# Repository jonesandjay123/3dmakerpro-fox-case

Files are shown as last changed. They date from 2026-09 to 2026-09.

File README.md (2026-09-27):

# 3dmakerpro-fox-case

A compact, low-profile, 3D-printable hard case for the **3DMakerpro FOX** scanner body.
V4 is **scanner only**; the cable and charger stay in the original accessory box for now.

| Closed | Lift-out access | One A1 mini plate |
|---|---|---|
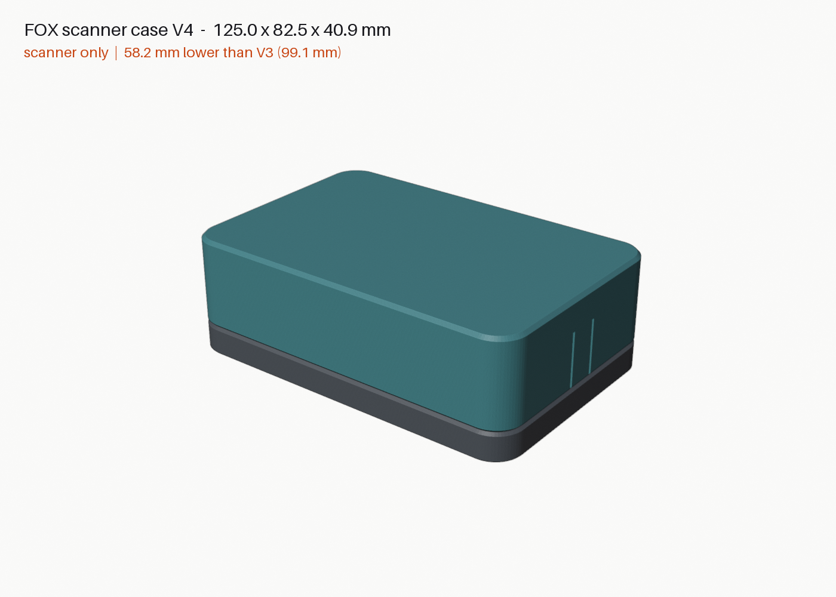
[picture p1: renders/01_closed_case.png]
closed
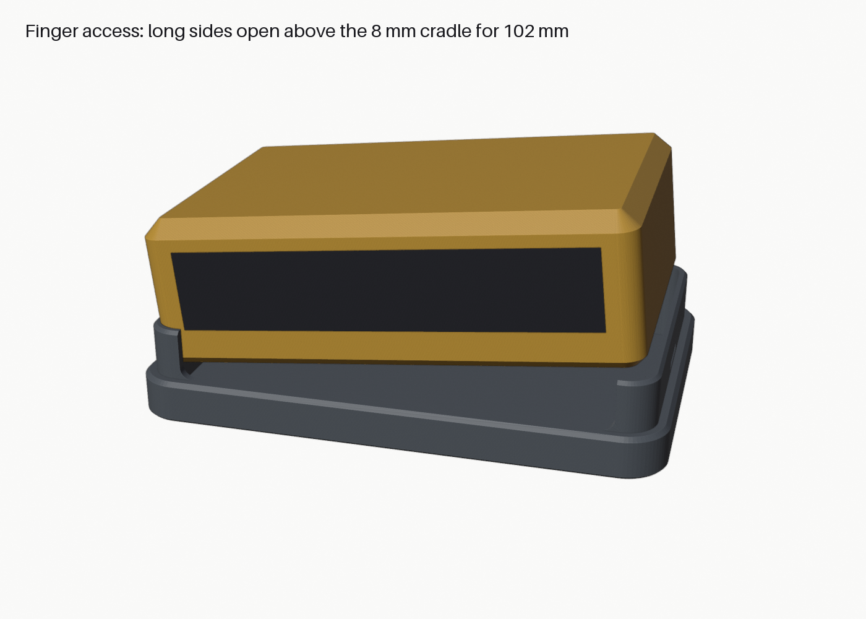
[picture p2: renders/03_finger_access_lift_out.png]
access
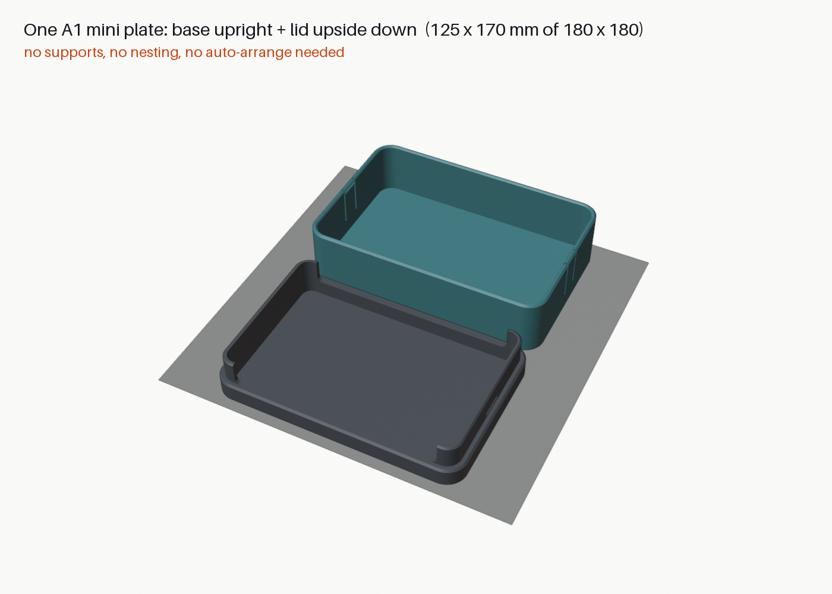
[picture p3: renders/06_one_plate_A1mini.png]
plate
|  |  |  |

## Status: V4 modelled and validated in CAD (not yet printed)

| | V4 |
|---|---|
| **Outside** | **125.0 × 82.5 × 40.9 mm** (58 mm lower than the V3 full-kit case) |
| **FOX cavity** | **115.5 × 73.0 mm** (R 5.25), from the physical fit test; 36.5 mm floor → lid ceiling |
| **Clearance** | ~1.5 mm above the FOX (35 mm stand-in); 0.3 mm per side; lens window faces open air |
| **Access** | shallow 8 mm cradle, **102 mm finger windows** on both long sides |
| **Lid** | low sleeve with **2 snap tabs** that click into the base (est. ~22 N to open) |
| **Print** | **one plate, one job, no supports**: base upright + lid upside down |
| **Filament** | ~89–102 g PLA |

Details, height budget, retention, validation and test plan: [`docs/design.md`](docs/design.md).

## Print

Open **`exports/fox_case_v4_A1mini_one_plate.3mf`** in Bambu Studio. The parts are already
placed; don't auto-arrange. Settings: 0.2 mm layers, 3 walls, 15 % infill, supports off, no brim.

Optional first: `exports/fox_fit_test_cradle_ring_v3.stl` (~9 g) to confirm the 73.0 mm width.

## Files

| Path | Contents |
|---|---|
| `scripts/build_fox_case.py` | Parametric build: named parameters; builds, validates, exports STL/3MF, saves the .blend |
| `scripts/run_all.py` / `scripts/render_views.py` / `scripts/annotate_renders.py` | Full pipeline / renders / dimension labels |
| `cad/fox_case.blend` | Editable Blender source |
| `exports/fox_case_v4_{base,lid}.stl` | Parts in print orientation |
| `exports/fox_case_v4_A1mini_one_plate.3mf` / `fox_case_v4_assembled.3mf` | One-plate job / assembled model |
| `exports/validation_report.json` | Parameters, measured dimensions, mesh, support, retention, plate and assembly checks |
| `renders/` | Closed, open, lift-out, exploded, sections, one-plate, snap tab, fit ring |
| `docs/design.md` | V4 design notes |
| `archive/v2`, `archive/v3` | Earlier full-kit (scanner + accessories) versions; also git tags `v1`–`v3` |
| `reference/` | Original photos, fit-test photos, V3 concept, third-party stand (unaltered) |

## Rebuild after changing a parameter

```bash
/Applications/Blender.app/Contents/MacOS/Blender -b cad/fox_case.blend --python scripts/run_all.py
```

```bash
uv run --with pillow python scripts/annotate_renders.py
```

Key parameters: `FOX_CAVITY_LENGTH/WIDTH`, `FOX_INTERNAL_HEIGHT`, `CRADLE_HEIGHT`, `WALL`, `FLOOR`,
`LID_WALL`, `LID_TOP`, `LID_CLEARANCE`, `TOWER_HEIGHT`, `RETENTION_ENGAGEMENT`, `FINGER_WINDOW_LENGTH`,
`PLATE_GAP`. `TOTAL_CASE_HEIGHT` is derived from them.

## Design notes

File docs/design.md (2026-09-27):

# FOX scanner case — design notes (V4: scanner-only, low profile)

**Scope:** a compact, protective hard case for the **3DMakerpro FOX scanner body only**. The cable
and charger are out of scope for now; they stay in the original black accessory box.

All geometry comes from [`scripts/build_fox_case.py`](../scripts/build_fox_case.py). Edit a parameter
and re-run it (see [README](../README.md)). Every number below is from `exports/validation_report.json`.

## V4 at a glance

| | V4 |
|---|---|
| **Outside** | **125.0 × 82.5 × 40.9 mm** (V3 full kit was 99.1 mm tall, so **−58.2 mm / −59 %**) |
| **FOX cavity** | **115.5 × 73.0 mm, R 5.25** (fit-test derived; measured on the model) |
| **FOX vertical space** | **36.5 mm**, floor → lid ceiling. With a 35 mm stand-in body that leaves **1.5 mm** above the FOX; the lid never touches it |
| **Cradle** | 8 mm capture height; **102 mm finger windows on both long sides** |
| **Lid retention** | 2 printed cantilever snap tabs (lid short ends) that click into grooves in the base end towers |
| **Print** | **one A1 mini plate, one job, no supports**: base upright + lid upside down, side by side |
| **Material** | 111 g solid-equivalent; expect **~89–102 g** at 3 walls / 15 % infill |

```
     ┌────────────────── LID: 2.4 wall, 2.4 flat top, snap tab at each end ──┐   z 40.9
     │                        1.5 mm clear above FOX                          │   z 38.5 ceiling
     │ ▐tower▌            FOX lies flat (36.5 mm space)            ▐tower▌    │
     └─▐     ▌▁▁▁▁▁ 8 mm cradle band; long sides open above ▁▁▁▁▁▐     ▌───┘   z 10.0 lid seat
       BASE: 2.0 floor · band · low C-shaped end towers (to z 22) with snap grooves    z 0
```

---

## 1. Evidence

* **Settled by the physical fit test** (printed ring, 115.5 × 72.5, R 5.25):
  - length fine with ~1 mm play;
  - width lightly gripped, so V3 widened it to **73.0**;
  - corners and the 8 mm cradle looked good.
* **FOX space 36.5 mm** is your measured requirement.
* V4 does **not** re-estimate the FOX from photos, the spec sheet or the third-party stand. That
  history is in `archive/` and the git tags.
* The FOX stand-in used for clearance checks (`FOX_PROXY` 114.4 × 72.4 × 35, R 5) is inferred. It
  isn't a design input.
* **Not yet physically verified:** the 73.0 mm width. The printed ring was 72.5.
  `exports/fox_fit_test_cradle_ring_v3.stl` is still exported for that check.

## 2. What changed from V3

| V3 (full kit) | V4 (scanner only) |
|---|---|
| Accessory tray 112.5 × 70 × 56 above the FOX | **removed**; accessory parameters no longer exist in the build |
| Towers 36.5 mm tall as a tray seat, plus tray lips | **towers only 20 mm** (lid guide + snap grooves), no lips, 0.8 mm lead-in |
| Lid ceiling above the tray (99.1 mm total) | **lid ceiling sits directly above the FOX space: 40.9 mm total** |
| 2 print jobs | **1 job, 1 plate** |
| Grey renders | teal lid / charcoal base, so V4 renders are easy to tell apart |

Kept as-is:
- cavity and corner logic;
- 8 mm cradle band and 102 mm finger windows;
- 1.5 mm tower stubs and R3 window corners, which keep the lens window clear;
- the snap-tab latch;
- the validation and export pipeline.

## 3. Height budget: 40.9 mm

| Layer | mm | |
|---|---|---|
| Base floor | 2.0 | 10 layers; the case bottom |
| FOX space (floor → lid ceiling) | 36.5 | measured requirement; includes the clearance above the FOX |
| Lid top | 2.4 | printed on the bed. At 2.4 mm a ~5 kg press on the middle of the lid is estimated to deflect ~0.5 mm (2.0 mm would be ~0.8 mm), well inside the 1.5 mm gap |
| **Total** | **40.9** | |

Nothing else stacks: the lid seats on the base band shoulder at z = 10, and its sleeve overlaps
the towers. Going lower means eating into the measured 36.5 mm, which V4 deliberately doesn't do.

## 4. Parts

### Base (125.0 × 82.5 × 22.0, printed upright)
* A **2.0 mm floor** with a **solid 10 mm band**, which has 4.75 mm walls on the long sides.
* **Cavity 115.5 × 73.0, R 5.25** with a flat floor.
* **Long sides open above the 8 mm cradle for 102 mm**, so you pinch the FOX by its long sides
  and lift it out (`renders/03_finger_access_lift_out.png`).
* The **C-shaped end towers** (2.0 mm wall) rise to z = 22 and guide the lid. Each carries a
  **detent groove** on its end face and a 0.8 mm lead-in chamfer on top. The towers stop 1.5 mm
  past the corner arcs, so the **lens window faces open air**. The sensor face stays ≥ 0.67 mm
  from the base; only the bezel sits below the 8 mm band.

### Lid (125.0 × 82.5 × 30.9, printed upside down)
* A **2.4 mm sleeve with a 2.4 mm flat top**. It has 0.35 mm clearance per side over the towers
  and a 0.8 mm lead-in at the mouth, and it seats on the base band at z = 10. Matching 1 mm
  chamfers at the joint form a thumb groove.
* Inside there is **1.5 mm above the FOX** (35 mm stand-in) and **2.45 mm in front of the sensor
  face**. The lid doesn't touch the FOX, even with the FOX lifted 0.5 mm.

### Retention: snap tabs
* **Tabs.** Two 1 mm slots, 20 mm long, at each lid end free a **10 mm × 2.4 mm cantilever tab**.
* **Bump.** Each tab has an inward bump that overlaps the tower face by
  **`RETENTION_ENGAGEMENT` = 0.4 mm**. Its lower ramp is 30° from vertical, for an easy click shut.
  Its upper ramp is 45°: firm to open, and the steepest face that prints without support.
* **Groove.** The matching groove in the base is 0.2 mm oversize. With the lid closed the bump
  sits in it without clashing.
* **Estimate** (PLA, beam theory, order of magnitude):
  - **closing ≈ 13 N**;
  - **opening ≈ 22 N** (≈ 2.3 kgf);
  - tab strain 0.36 %.
  - The FOX plus base weigh ~0.25 kg, so lifting the closed case by the lid won't drop the base.
* **Tuning:** use 0.3 for a lighter feel (~17 N to open), or 0.5 for a firmer hold (~28 N).
* The latch adds no external structure: the tabs are flush with the lid wall.

## 5. Printing: one A1 mini plate

* `exports/fox_case_v4_A1mini_one_plate.3mf`: **base upright** and **lid upside down**, side by
  side. It uses **125 × 170 mm** of the 180 × 180 bed, with a 5 mm gap between parts and ≥ 5 mm
  margins. Open it as-is; **no auto-arrange needed**.
* **Support-free.** 0 mm² of down-facing surface steeper than 45° on both parts, and no bridges.
* **Big first layers.** The base puts 9,990 mm² on the bed and the lid 9,750 mm², so no brim is needed.
* Settings: 0.2 mm layers, 3 walls, 15 % infill, PLA or PETG.
* Filament: base 48 g + lid 63 g = **111 g solid-equivalent**, so expect **~89–102 g**.
* Individual STLs (`fox_case_v4_base.stl`, `fox_case_v4_lid.stl`) are exported in the same
  orientations.

## 6. Validation

| Check | Result |
|---|---|
| Cavity (measured by ray cast on the model) | **115.5 × 73.0 mm** ✓ |
| Floor → lid ceiling (measured) | **36.5 mm** ✓ |
| FOX top clearance (35 mm stand-in) | **1.5 mm**; `lid_presses_on_fox: false` |
| FOX stand-in ↔ cradle wall | 0.3 mm per side (0.55 per end) |
| Sensor face ↔ base / lid | 0.67 / 2.45 mm |
| Finger access | 102 mm on both long sides, above the 8 mm band |
| Lid / base fit | 0.35 mm per side on the towers; lid seats on the band; no clash |
| Positive retention | bump seated in groove, 0.4 mm engagement |
| Watertight / non-manifold / self-intersections / islands | 0 / 0 / 0 / 1 on every part (also on re-imported STLs) |
| Min wall (1st percentile) | base 2.0, lid 2.4 |
| Supports | none (both parts `support_free: true`) |
| Per-part A1 mini fit | ✓ base 125 × 82.5 × 22.0, lid 125 × 82.5 × 30.9 |
| One-plate fit | ✓ bbox 27.5–152.5 × 5–175 mm, 5 mm between parts, no clash |
| Outside | **125.0 × 82.5 × 40.9 mm** |
| Material | 111 g solid-equivalent, ~89–102 g sliced |

## 7. Assembly and use

1. Drop the FOX in, sensor face toward either long side.
2. Push the lid straight down until both tabs click.
3. To open, hold the base band and pull the lid up.
4. Lift the FOX out by pinching its long sides through the windows.

## 8. Remaining physical tests

1. **Width 73.0.** Print `fox_fit_test_cradle_ring_v3.stl` (~9 g) or the full plate, and confirm
   the FOX drops in and lifts out without friction.
2. **Top clearance.** 36.5 mm is reserved. If the FOX itself is close to 36.5 mm tall, there's
   almost no Z margin; tell me and I'll add some (+1 mm on the case).
3. **Snap feel.** Tune `RETENTION_ENGAGEMENT` (0.3–0.5) to taste.
4. **Lens window vs the 8 mm band** (fine in the ring test).

## 9. History

| | V1 | V2 | V3 | **V4** |
|---|---|---|---|---|
| Scope | FOX + accessories | same | same | **FOX only** |
| Outside (mm) | 125 × 82 × 113.3 | 125 × 82 × 130.5 | 125 × 82.5 × 99.1 | **125 × 82.5 × 40.9** |
| Cavity | 115.5 × 72.5 | 115.5 × 72.5 | 115.5 × 73.0 | **115.5 × 73.0** |
| Print | 2 plates | 1 plate (nested) | 2 plates | **1 plate** |
| Retention | slip | slip | snap tabs | **snap tabs** |

* Git tags `v1`, `v2`, `v3`.
* `archive/v2/` and `archive/v3/` hold the printable files, key renders, and V3's design notes
  and build script.

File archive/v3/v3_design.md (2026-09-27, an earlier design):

# FOX carrying case — design notes (V3: compact)

Goal: one rigid, compact, FDM-printable case that carries the **3DMakerpro FOX scanner, its
cable and its charger together**. Printer: Bambu Lab A1 mini (180 × 180 × 180 mm per part).

All geometry comes from [`scripts/build_fox_case.py`](../scripts/build_fox_case.py). Edit a parameter
and re-run it (see [README](../README.md)). Numbers below are current V3 values, taken from
`exports/validation_report.json`.

## V3 at a glance

| | V3 |
|---|---|
| **Outside** | **125.0 × 82.5 × 99.1 mm** (V2 was 130.5 mm tall, so **−31.4 mm**) |
| **FOX cavity** | **115.5 × 73.0 mm, R 5.25**, from the physical fit test |
| **FOX vertical space** | **36.5 mm** clear (floor top → tray underside) |
| **Accessory tray** | **112.5 × 70.0 × 56 mm inside**, **one open bin, no divider** |
| **Lid retention** | 2 printed cantilever snap tabs (lid short ends) that click into grooves in the base |
| **Print** | 2 jobs, no supports: (A) base + tray, (B) lid upside down |
| **Material** | ≈ 249 g solid-equivalent; expect ~195–225 g at 3 walls / 15 % infill |

---

## 1. Evidence (V3 order of authority)

1. **Physical fit test (new, primary).** You printed the V2 ring (cavity 115.5 × 72.5, R 5.25):
   * **Length 115.5:** a little over ~1 mm total free play. Kept.
   * **Width 72.5:** it fits, but grips the FOX lightly. **Widened by 0.5 → 73.0**, so the FOX drops in
     without friction.
   * **Corners R 5.25:** behaved well. Kept.
   * **Cradle height (8 mm band):** looked right. Kept.
2. **Your physical height measurement:** reserve **36.5 mm** for the scanner region. It's used as
   the clear height from the base floor to the tray underside.
3. **Your accessory measurement:** the charger is **~56 wide × 52 tall**. Charger + cable laid out
   in a row need ~56 × 52 × 172 mm. **Your decision:** keep the 125 × 82 footprint, don't reproduce
   the 172 mm row. The tray is one open bin **~56 mm deep** (charger at one end, cable coiled freely
   beside it), with a total height target of ~98–100 mm.
4. The V1/V2 photo analysis, third-party stand STL and spec sheet are superseded wherever they
   conflict with 1–3. The history is in §9.

The FOX stand-in body used for clearance checks (`FOX_PROXY` = 114.4 × 72.4 × 35, R 5) is
*inferred* from the ring test. It isn't a design input.

## 2. What changed from V2 and why

| V2 driver | V3 |
|---|---|
| Whole case on one plate, no supports, at any height cost (roof + nested tray → 130.5 mm) | **Dropped.** Two print jobs are fine; carrying a smaller case every day matters more |
| Tray volume ≥ cardboard box (539 cm³) | **Dropped.** Tray sized for the real charger (52 tall) + free cable coil |
| Cavity 115.5 × 72.5, space 36.5 | **115.5 × 73.0** (fit test), 36.5 kept as a hard requirement |
| Slip-fit lid | **Snap-tab retention** |
| Lid printed mouth-down with a 45° roof | Lid printed **upside down with a flat top**: big first layer, no bridge, lower |
| Floor 2.4, tray floor 2.0, lid top 2.4 | 2.0 / 1.6 / 2.0 (height trimmed where it isn't structural) |

## 3. Height budget: why 99.1 mm is the practical minimum

| Layer (bottom → top) | mm | Why it can't shrink |
|---|---|---|
| Base floor | 2.0 | 10 solid layers; also the case bottom |
| FOX space | 36.5 | your measured requirement |
| Tray floor | 1.6 | 8 layers; the tray is stiffened by its 2 mm walls |
| Tray inner depth | 56.0 | charger 52 + ~4 headroom (you chose 55–58; 56 used) |
| Tray rim → lid ceiling | 1.0 | limits tray lift; keeps the FOX captured |
| Lid top | 2.0 | printed on the bed; 10 layers |
| **Total** | **99.1** | |

The only big lever left is the tray depth: each 1 mm off `ACCESSORY_TRAY_HEIGHT` takes 1 mm off
the case. If your charger can lie on a thinner face, set the parameter and rebuild (at a 34 mm
depth the case would be ~77 mm tall).

## 4. Architecture

```
        ┌───────────────── LID (flat top, 2.4 wall, snap tabs at both ends) ─┐  z 99.1
        │  ┌──────── TRAY: ONE open bin, 112.5 × 70 × 56 inside ────────┐   │  z 96.1 rim
        │  │  charger (52 tall) at one end · cable coiled freely beside   │   │
        │  └──────────────────── tray floor 1.6 ──────────────────────────┘   │  z 38.5
        │ ▐tower▌      FOX lies flat, 36.5 mm space            ▐tower▌      │
        └─▐     ▌▁▁▁▁ 8 mm cradle band (long sides open above) ▁▁▐     ▌─────┘  z 10.0 lid seat
          BASE: 2.0 floor · band · C-shaped end towers · snap grooves         z 0
```

* **Base.** A 2.0 mm floor and a solid 10 mm band (walls 4.75 mm on the long sides). Above it, two
  **C-shaped end towers** (2.0 wall) rise to the tray seat at z = 38.5. **Both long sides are open
  above the 8 mm cradle for 102 mm**, so you pinch the FOX by its long sides to lift it out. The
  tower stubs stop 1.5 mm past the corner arcs, so the lens window faces open air.
  2.5 mm lips on the tower tops locate the tray and carry a 0.6 mm lead-in for the lid.
* **FOX cavity 115.5 × 73.0, R 5.25** with a flat floor. With the stand-in body that leaves
  ~0.55 mm per end and ~0.3 mm per side. The sensor face stays ≥ 0.67 mm clear of the base and
  2.45 mm clear of the lid; only the bezel is below the 8 mm band.
* **Tray.** **One open bin with no divider, rib or molded pocket.** It's 116.5 × 74.0 × 57.6 mm
  outside and **112.5 × 70.0 × 56 mm inside (≈ 440 cm³)**. It sits on the towers, 1.5 mm
  above the FOX, so it also keeps the FOX from lifting out of the cradle.
* **Lid.** A 2.4 mm sleeve with 0.35 mm clearance per side over the towers and a 0.8 mm lead-in at
  the mouth. It rests on the base band shoulder at z = 10. A matching 1 mm chamfer at the joint
  forms a thumb groove.

### 4.1 Lid retention: snap tabs

* **Tabs.** Each short end of the lid has two 1 mm slots, 20 mm long from the mouth up. They free
  a **10 mm wide, 2.4 mm thick cantilever tab**.
* **Bump.** Near the tab's free end, an inward bump stands **0.35 + 0.4 mm** proud of the lid wall.
  The lower ramp is 30° from vertical, for easy closing. The upper ramp is 45°, which is firm to
  open and is also the steepest face the lid can print without support.
* **Groove.** A matching groove, 0.2 mm oversize, is cut into each base tower end wall. The bump
  overlaps the tower face by **0.4 mm**, and that overlap is the click.
* **Beam estimate** (PLA, E ≈ 3.5 GPa, μ ≈ 0.3, order of magnitude only):
  - **closing** ≈ 13 N total;
  - **opening** ≈ 22 N total (≈ 2.3 kgf);
  - tab-root strain 0.36 %, far below PLA's limit.

  The FOX plus base weigh ~0.3 kg, so the base will not fall away when you lift the closed case by
  the lid. You open it deliberately by holding the band and pulling the lid.
* **Tuning:** `LID_RETENTION["engage"]` (0.4). Use 0.3 if it's too stiff, or 0.5 for a firmer hold.

See `renders/07_snap_tab_section.png` (bump seated in the groove) and `07b_lid_underside_tabs.png`.

## 5. Printing

| Job | Part | Orientation | First layer | Supports |
|---|---|---|---|---|
| **A** | Base (125 × 82.5 × 41.0) | upright, floor on bed | 9,990 mm² | none |
| **A** | Tray (116.5 × 74.0 × 57.6) | upright, floor on bed | 8,370 mm² | none |
| **B** | Lid (125 × 82.5 × 89.1) | **upside down**, flat top on bed | 9,750 mm² | none |

* Ready-made plates: `exports/fox_case_v3_plate_A_base_and_tray.3mf` and
  `exports/fox_case_v3_plate_B_lid.3mf`. Individual STLs are already in print orientation.
* **Support-free.** 0 mm² of down-facing surface steeper than 45° on every part, and no bridges.
  The only non-vertical features:
  - the 45° release ramps on the lid bumps and in the base grooves;
  - the ≤45° chamfers;
  - the finger-window bottoms, which curve *away* from the material.
* Suggested settings: 0.2 mm layers, 3 walls, 15 % infill, PLA or PETG, no brim needed.
* **Material:** base 56 + tray 68 + lid 126 = **249 g solid-equivalent**. Expect **~195–225 g**
  sliced. Use the slicer's number for time.

## 6. Validation (`exports/validation_report.json`)

| Check | Result |
|---|---|
| FOX cavity | 115.5 × 73.0 mm, R 5.25 ✓ |
| FOX vertical space | 36.5 mm ✓ (stand-in 35 mm body → 1.5 mm to the tray) |
| FOX stand-in ↔ cradle | 0.3 mm per side, no clash |
| Sensor face ↔ base / lid | 0.67 / 2.45 mm |
| Finger access | 102 mm windows, both long sides, above the 8 mm band |
| Tray is divider-free | **568 / 568** grid rays dropped into the tray reach the floor unobstructed |
| Charger (52 × 56 × 52) + cable-coil stand-in (54 × 64 × 40) | both fit side by side, with no clash with each other, the tray or the lid; charger top 4.85 mm below the lid |
| Lid / base retention | bump seated in groove without clash; 0.4 mm engagement |
| Watertight / islands / self-intersections | 0 non-manifold edges, 1 island, 0 self-intersections on every part (also re-checked on re-imported STLs) |
| Min wall (1st percentile) | base 1.2 (lips), tray 1.6 (floor), lid 2.0 (top) |
| A1 mini per part / plates | all ✓; plate A 125 × 164.5, plate B 125 × 82.5 |
| Assembly clashes | none (resting contacts checked with a 0.02 mm lift) |

**What the checks don't prove.** The charger and cable stand-ins show the space is
*plausible*. They are not a packing proof. The charger's third dimension (depth) wasn't measured
and is assumed to be ≤ 52 mm. The cable's real coiled shape varies.

## 7. Assembly and use

1. Drop the FOX into the base cradle, sensor face toward either long side.
2. Put the tray on the towers (it drops between the lips). Charger at one end, cable coiled freely.
3. Push the lid down until both tabs click. To open, hold the base band and pull the lid up.

## 8. What still needs physical testing

1. **Width 73.0.** Optionally reprint `exports/fox_fit_test_cradle_ring_v3.stl` (~9 g) to confirm
   the FOX now drops in and lifts out freely.
2. **Charger + cable in the 112.5 × 70 × 56 tray.** Especially the charger's depth, and whether the
   cable coils into the ~58 × 70 mm left beside it.
3. **Snap-tab feel.** How firm it is to open and close. Tune `engage`.
4. **FOX top clearance.** 36.5 mm is reserved. If the FOX itself is close to 36.5 mm tall, there's
   no Z margin, so tell me and I'll add some.
5. **Lens window vs the 8 mm band** (it looked fine in the ring test).

## 9. History

| | V1 | V2 | **V3** |
|---|---|---|---|
| Outside (mm) | 125 × 82 × 113.3 | 125 × 82 × 130.5 | **125 × 82.5 × 99.1** |
| FOX cavity | 115.5 × 72.5 | 115.5 × 72.5 | **115.5 × 73.0** (fit-tested) |
| Accessory tray | 539 cm³ (box volume) | 539 cm³ | **one open bin, 56 deep** |
| Print | 2 plates | 1 plate, nested | **2 plates** |
| Retention | slip fit | slip fit | **snap tabs** |

* V1 and V2 are tagged in git (`v1`, `v2`).
* V2's printable files and key renders are kept in `archive/v2/`. That includes the ring used for
  the physical test: `archive/v2/fox_fit_test_cradle_ring.stl`.
* V1/V2 evidence work (perspective-corrected photo measurements, third-party stand analysis:
  113.0 mm between its lips) is in the git history of this file.

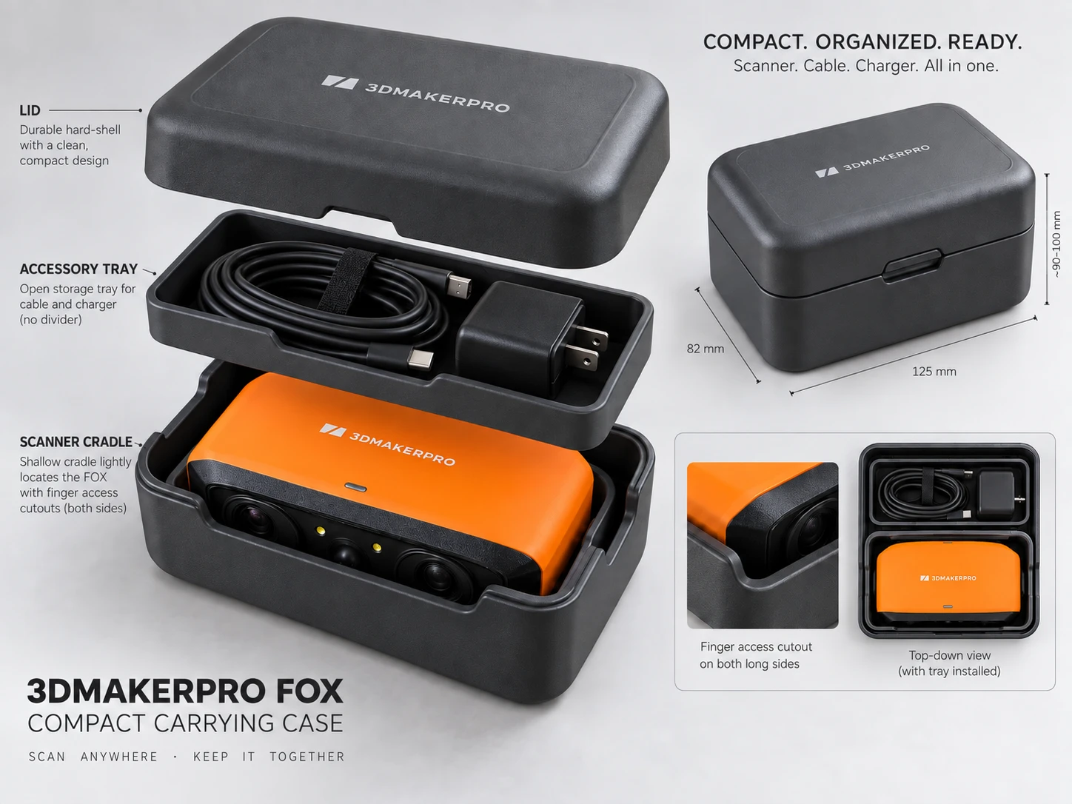
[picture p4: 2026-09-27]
reference/concept/v3_concept_no_divider.webp

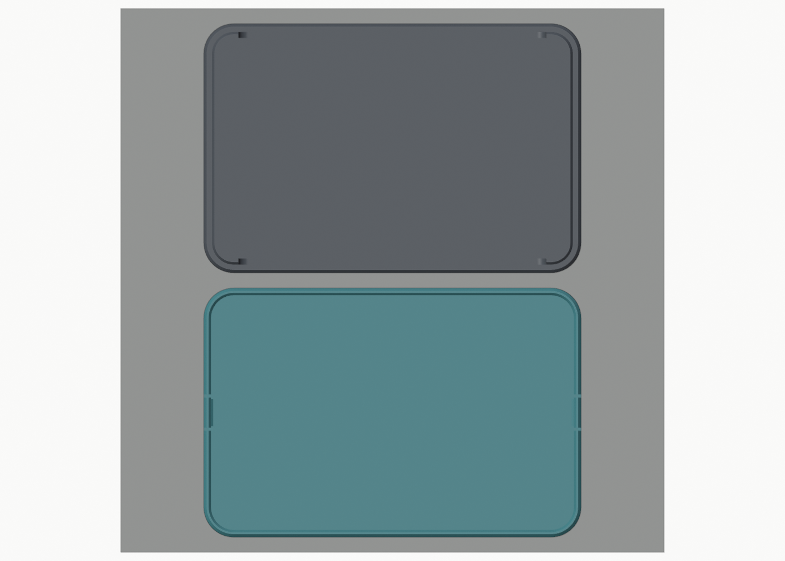
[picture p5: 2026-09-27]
renders/06b_one_plate_top.png

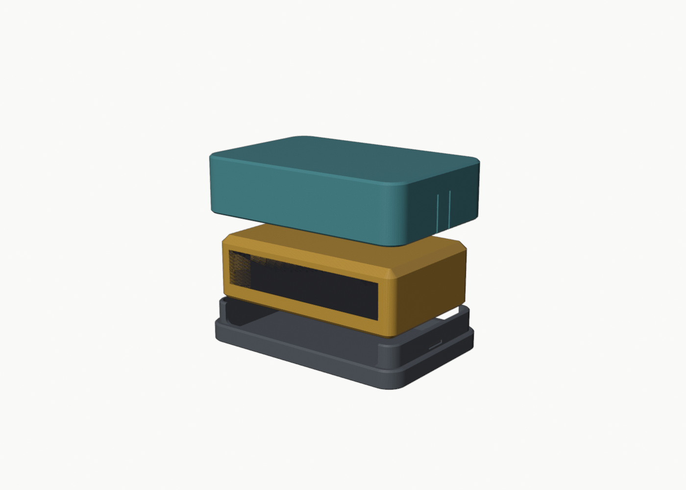
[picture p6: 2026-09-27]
renders/04_exploded.png

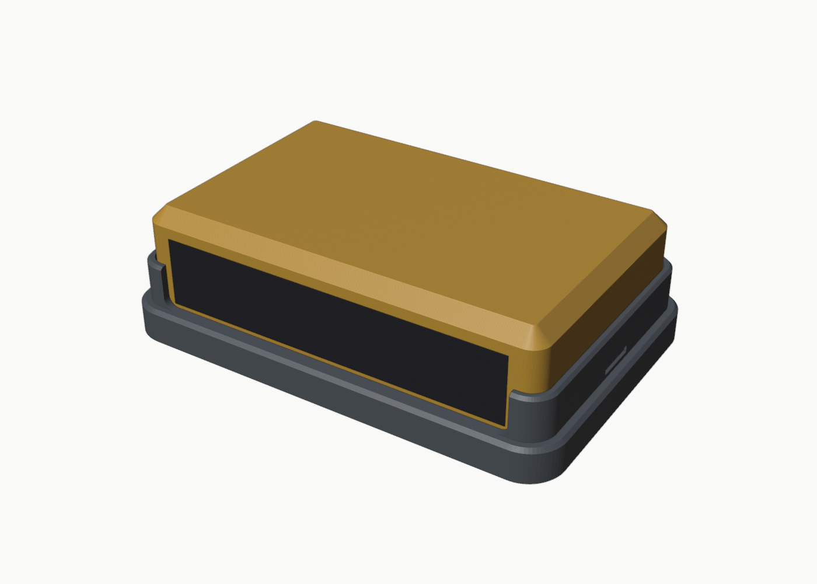
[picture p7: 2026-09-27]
renders/03b_fox_in_cradle.png

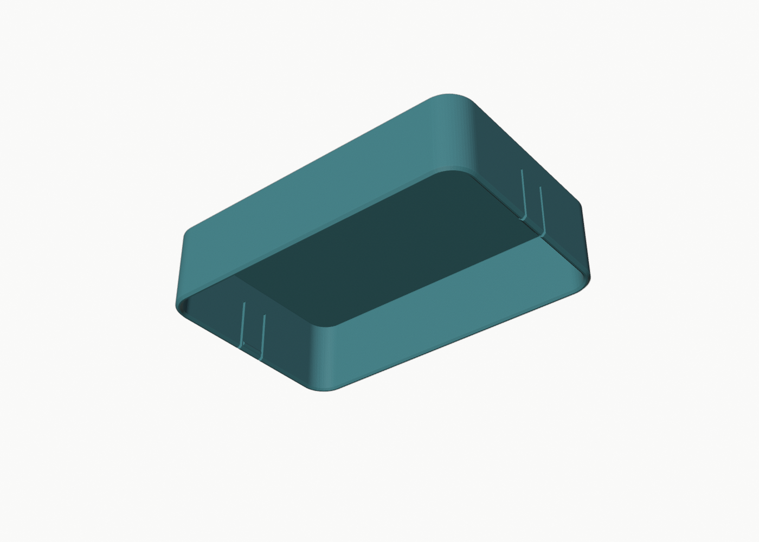
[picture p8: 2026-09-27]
renders/07b_lid_underside_tabs.png

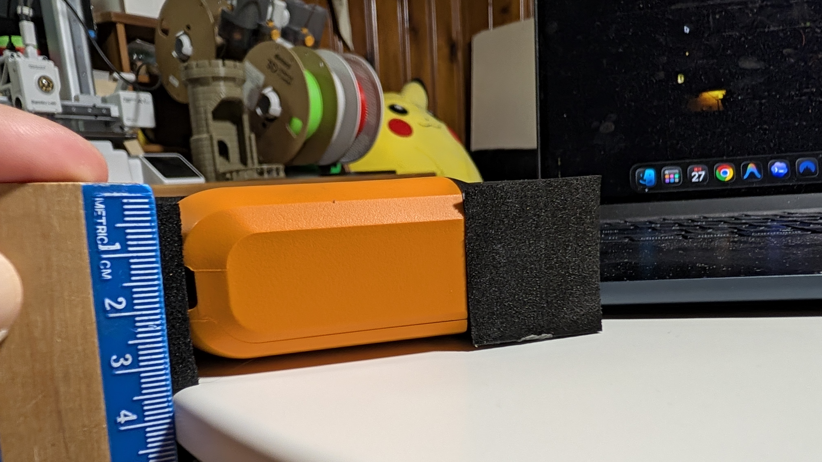
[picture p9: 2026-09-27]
reference/photos/PXL_20260927_174231056.MACRO_FOCUS.jpg

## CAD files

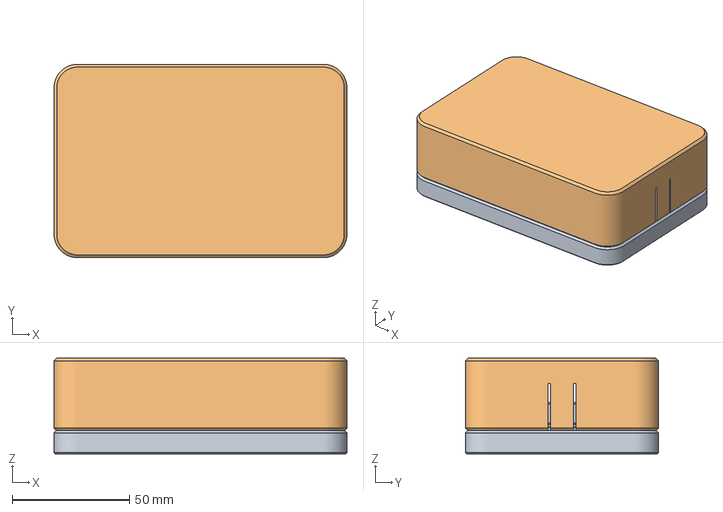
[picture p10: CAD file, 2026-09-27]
exports/fox_case_v4_assembled.3mf
125.0 x 82.5 x 40.9 mm
Base
Lid

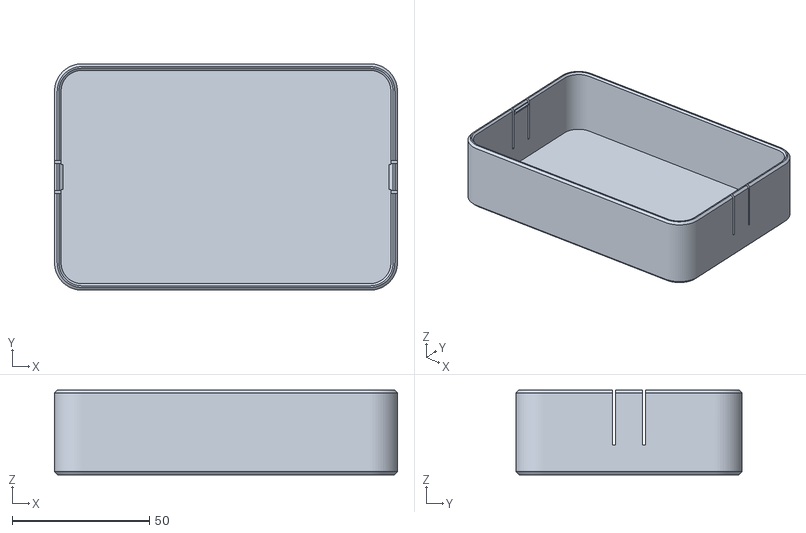
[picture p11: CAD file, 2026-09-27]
exports/fox_case_v4_lid.stl
125.0 x 82.5 x 30.9

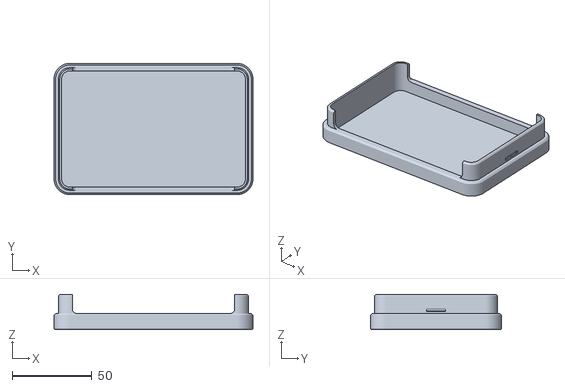
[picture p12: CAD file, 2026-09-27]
exports/fox_case_v4_base.stl
125.0 x 82.5 x 22.0

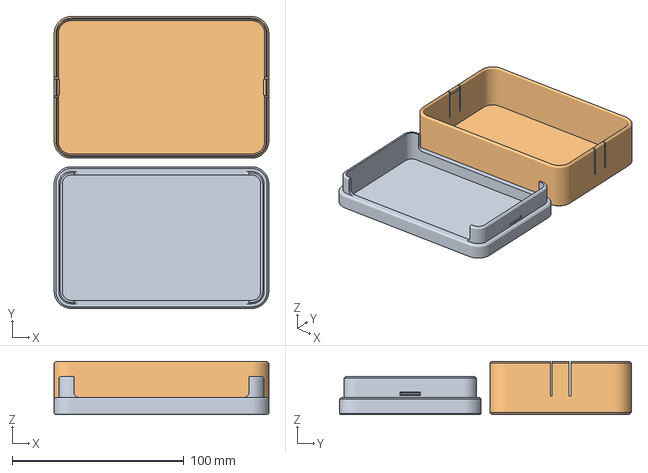
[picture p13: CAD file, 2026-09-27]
exports/fox_case_v4_A1mini_one_plate.3mf
125.0 x 170.0 x 30.9 mm
Base
Lid

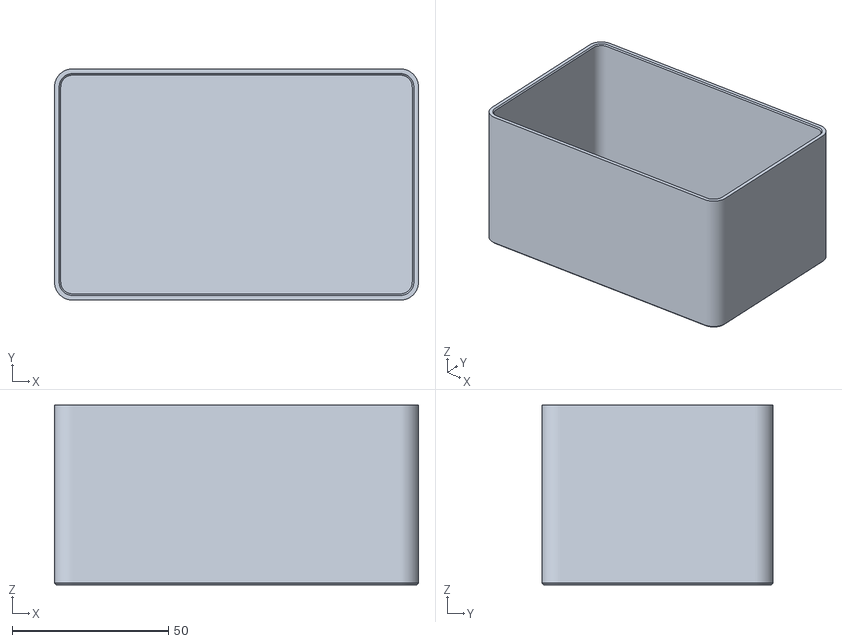
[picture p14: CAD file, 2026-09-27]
exports/fox_case_v3_accessory_tray.stl
116.5 x 74.0 x 57.6

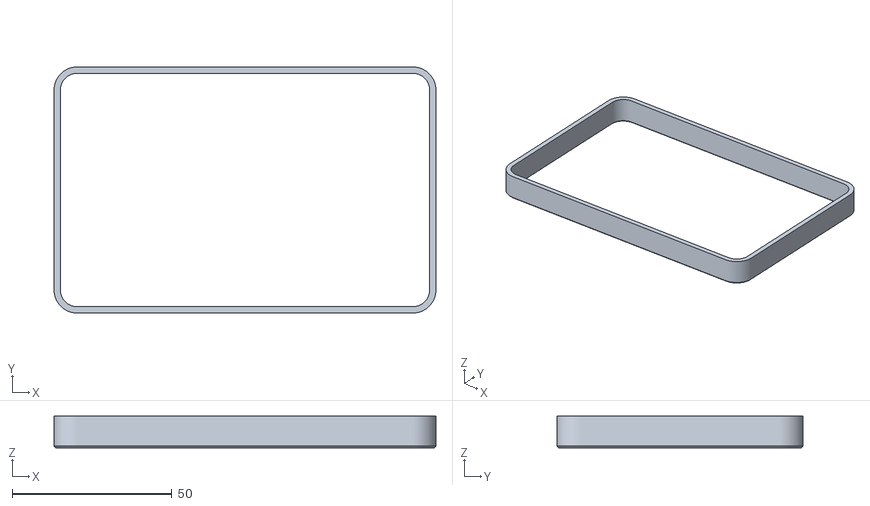
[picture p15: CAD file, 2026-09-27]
exports/fox_fit_test_cradle_ring_v3.stl
119.5 x 77.0 x 10.0

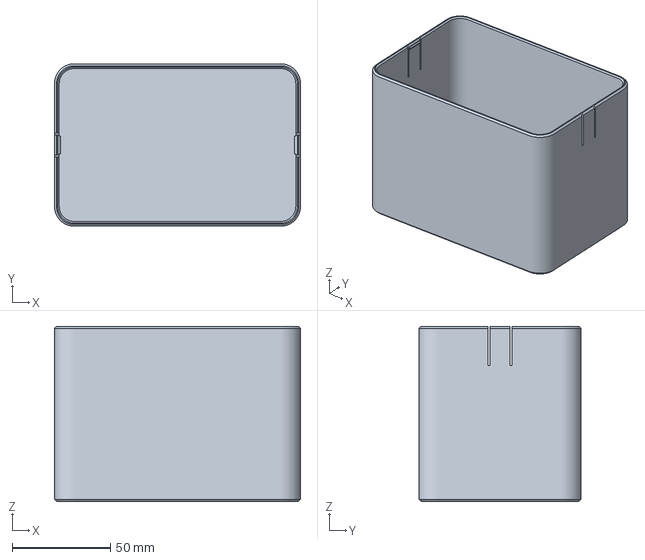
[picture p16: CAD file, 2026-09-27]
exports/fox_case_v3_plate_B_lid.3mf
125.0 x 82.5 x 89.1 mm

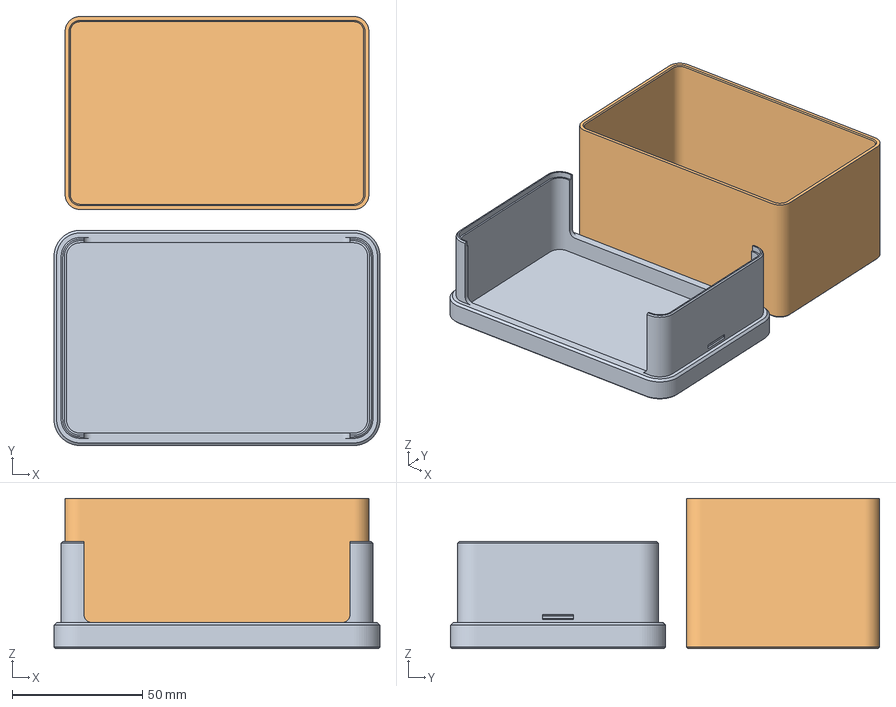
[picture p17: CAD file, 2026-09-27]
exports/fox_case_v3_plate_A_base_and_tray.3mf
125.0 x 164.5 x 57.6 mm
Base
Tray

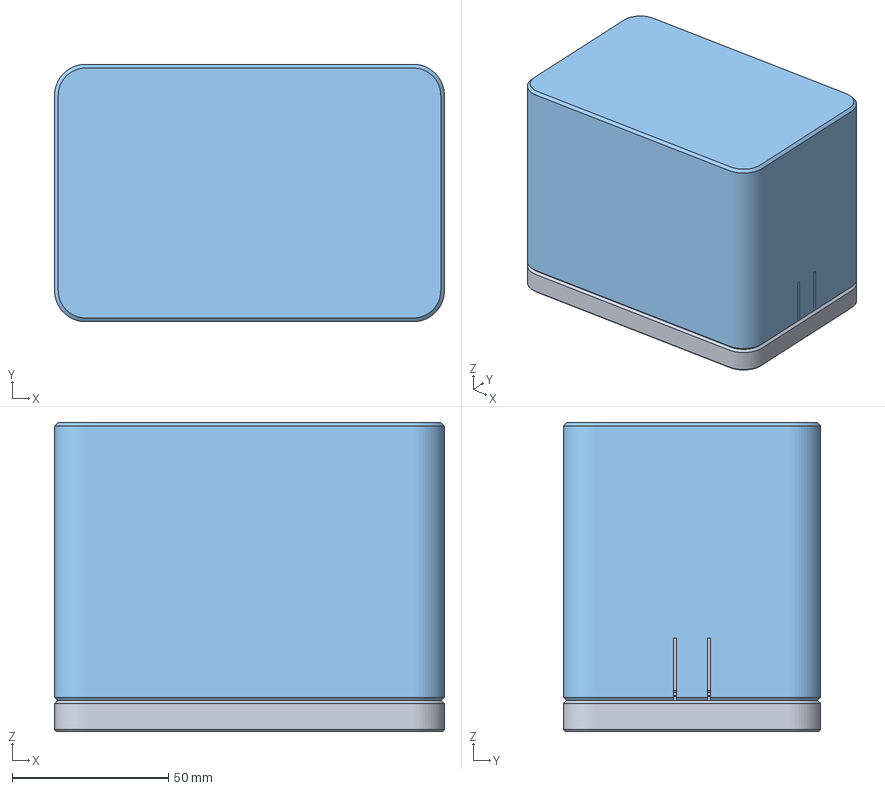
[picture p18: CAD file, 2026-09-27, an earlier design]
archive/v3/fox_case_v3_assembled.3mf
125.0 x 82.5 x 99.1 mm
Base
Tray
Lid

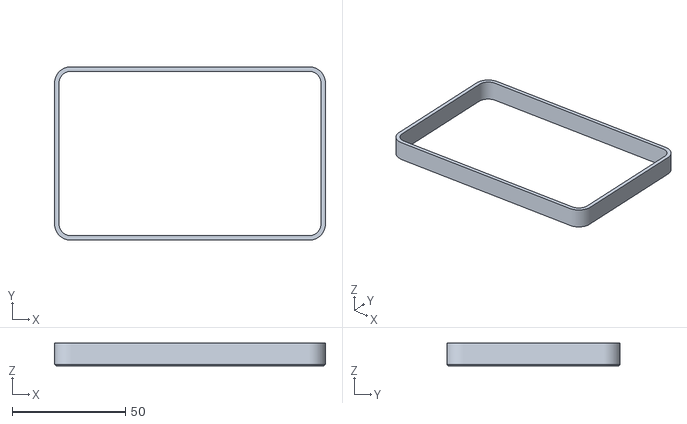
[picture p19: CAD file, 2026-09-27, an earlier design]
archive/v2/fox_fit_test_cradle_ring.stl
119.5 x 76.5 x 10.0

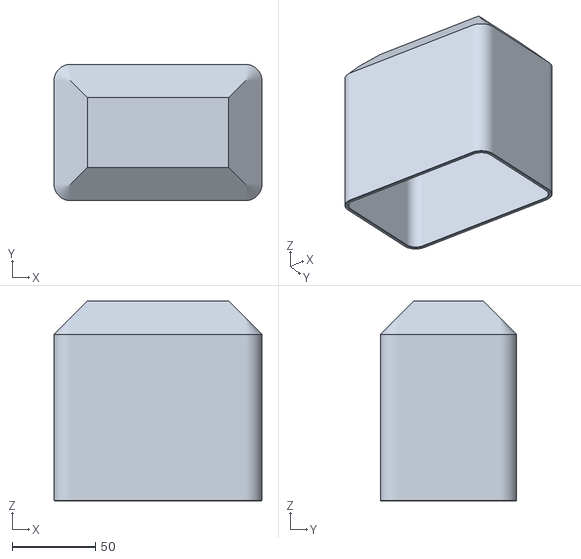
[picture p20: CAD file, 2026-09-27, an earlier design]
archive/v2/fox_case_lid.stl
125.0 x 82.0 x 120.1

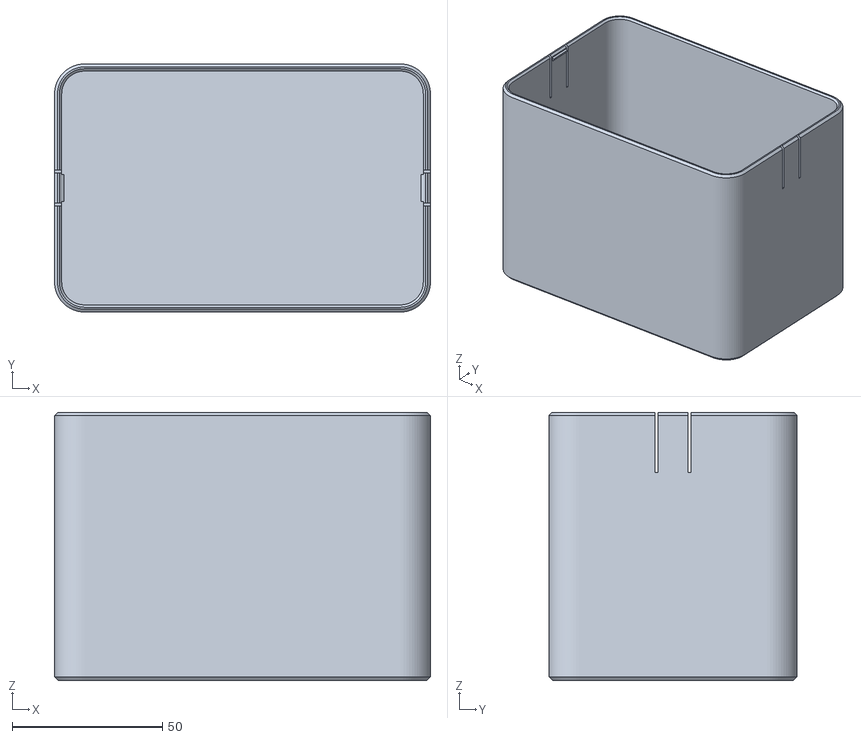
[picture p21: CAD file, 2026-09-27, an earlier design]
archive/v3/fox_case_v3_lid.stl
125.0 x 82.5 x 89.1

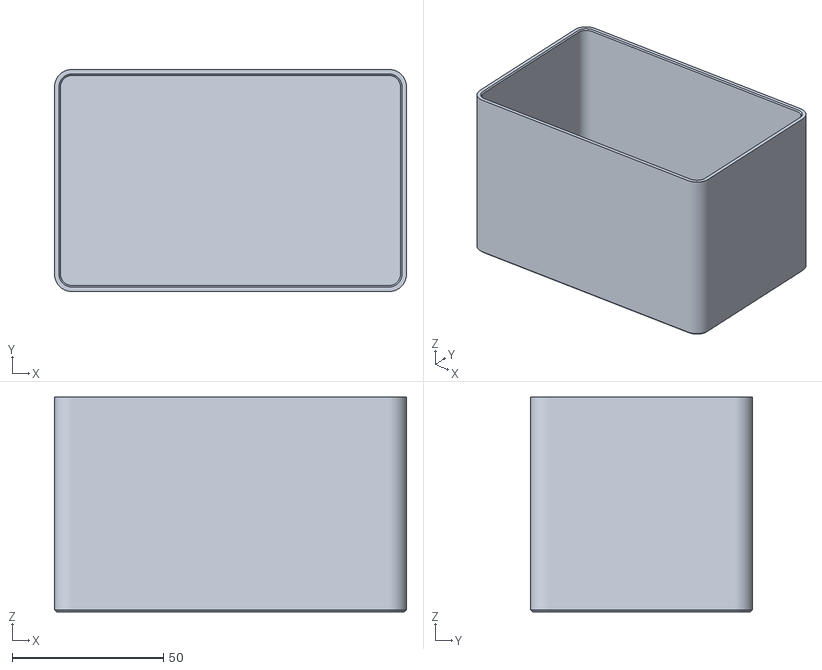
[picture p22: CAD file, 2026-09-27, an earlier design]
archive/v2/fox_case_accessory_tray.stl
116.5 x 73.5 x 71.0

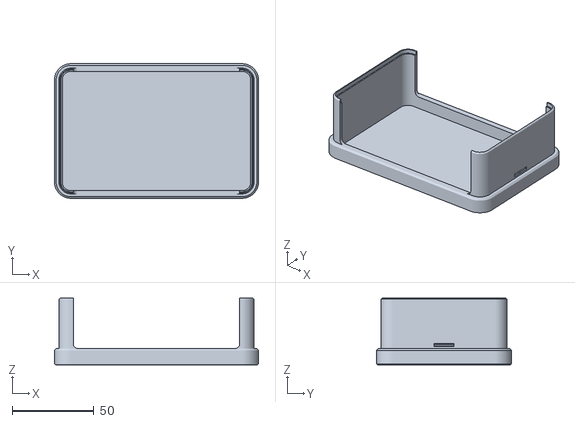
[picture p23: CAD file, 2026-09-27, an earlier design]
archive/v3/fox_case_v3_base.stl
125.0 x 82.5 x 41.0

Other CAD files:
archive/v2/fox_case_base.stl
archive/v2/fox_case_A1mini_one_plate.3mf
archive/v2/fox_case_A1mini_one_plate.stl
cad/fox_case.blend
exports/fox_case_A1mini_one_plate.3mf
exports/fox_case_A1mini_one_plate.stl
exports/fox_case_base.stl

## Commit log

2026-09-27 FOX carrying case V1: stacked base/tray/lid + fit-test ring
    - Reference audit: ruler photos with perspective-corrected measurements,
    third-party stand STL analysis (113.0 mm lip gap), manufacturer spec cross-check
    - Layout study: stacked (125 x 82 x 113 mm) beats side-by-side (~62% less
    footprint; side-by-side exceeds the A1 mini bed)
    - Parametric Blender build script: base with 8 mm cradle band + C-shaped end
    towers and 97 mm finger windows, accessory tray sized to the original black
    box volume (539 cm3), slip-over lid, fit-test ring sharing the cavity params
    - Validation: watertight, single island, no self-intersections, no overhangs,
    no assembly clashes, clearances verified; STL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
    [fox_case_v1.blend, fox_case_v1_accessory_tray.stl, fox_case_v1_base.stl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]
2026-09-27 V2: whole case prints on one A1 mini plate, support-free
    - Lid now prints mouth-down in its use orientation: 45-deg chamfered roof
    (self-supporting) closing to a 40 mm bridge, so it needs no support
    - Accessory tray prints nested inside the lid (1.85 mm gap), freeing the
    bed: plate = base + (lid with tray) = 125 x 172 mm of 180 x 180
    - Exact 45-deg roof offset at the corners; tray-to-roof gap 1.5 mm
    - Lead-in chamfer moved to the base lips; lid mouth chamfers reduced to
    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
    [fox_case.blend, fox_case_A1mini_one_plate.3mf, fox_case_A1mini_one_plate.stl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]
2026-09-27 V3: compact case (99.1 mm tall), fit-tested cavity, open tray, snap-tab lid
    - FOX cavity 115.5 x 73.0 (R 5.25) from the printed V2 ring test: length
    kept, width +0.5 so the FOX drops in without friction; 36.5 mm FOX space
    - Accessory tray is ONE open bin, no divider: 112.5 x 70.0 x 56 inside for
    the 52 mm charger + freely coiled cable; cardboard-box volume target dropped
    - One-plate constraint dropped: lid back to a flat top printed upside down,
    2 print jobs (A: base + tray, B: lid), all support-free
    - Total height 130.5 -> 99.1 mm at the same 125 x 82.5 footprint
    - Lid retention: two cantilever snap tabs in the lid ends + matching grooves
    in the base towers (45-deg release ramp, est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
    [fox_case.blend, fox_case_A1mini_one_plate.3mf, fox_case_A1mini_one_plate.stl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]
2026-09-27 V4: scanner-only low-profile case, 40.9 mm tall, one A1 mini plate
    - Scope reduced to the FOX body; accessory tray and all accessory
    parameters removed from the active build (V3 archived in archive/v3)
    - Case 125.0 x 82.5 x 40.9 mm (V3 full kit: 99.1 mm): floor 2.0 +
    measured 36.5 mm FOX space + 2.4 mm lid top
    - Cavity 115.5 x 73.0 R5.25 (fit-test derived), 8 mm cradle, 102 mm
    finger windows on both long sides, lens window faces open air
    - End towers cut to 20 mm: lid guide + snap grooves; V3 snap-tab latch
    kept (0.4 mm engagement, est. ~22 N to open)
    - One-plate job: base upright + lid upside down side by side, 125 x 170 mm
    of the bed, support-free, ~89-102 g
    - Validation measures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
    [fox_case.blend, fox_case_v3_accessory_tray.stl, fox_case_v3_assembled.3mf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]
